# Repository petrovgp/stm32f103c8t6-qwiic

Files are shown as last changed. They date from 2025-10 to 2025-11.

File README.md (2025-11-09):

# STM32F103C8T6 Qwiic-Compatible Breakout Board

A compact and versatile **STM32F103C8T6** breakout board designed in **KiCad 9**, featuring multiple Qwiic-compatible connectors for easy sensor and peripheral integration. Ideal for prototyping, embedded development, and educational use.

## 📸 Board design
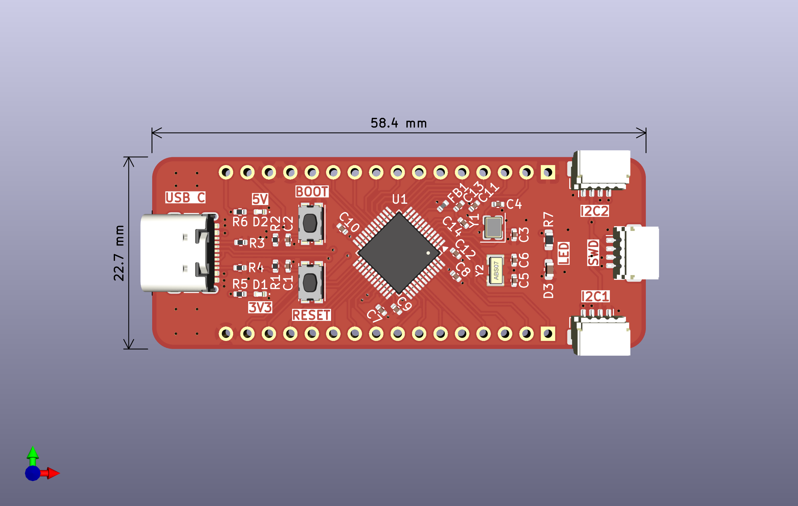
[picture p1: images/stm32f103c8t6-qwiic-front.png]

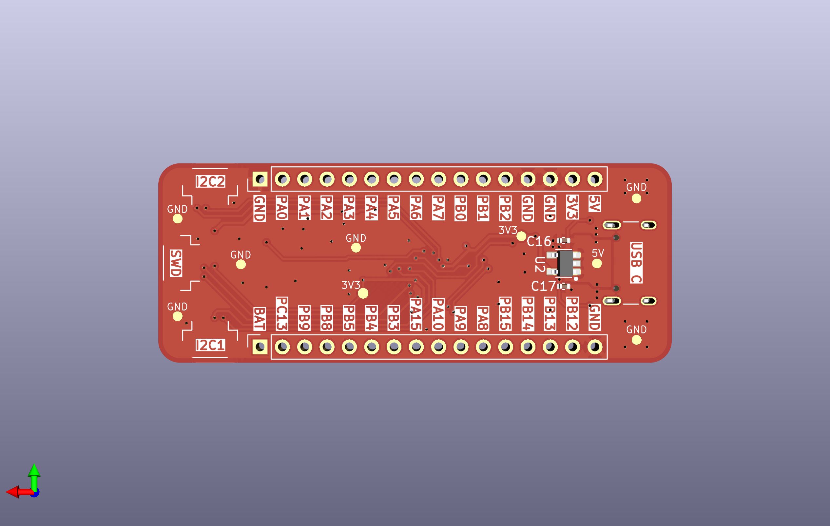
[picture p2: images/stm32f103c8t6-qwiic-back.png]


## 🧠 Features

### ⚡ Core
- **STM32F103C8T6** ARM Cortex-M3 microcontroller (72 MHz, 64 KB Flash, 20 KB RAM)
- Compact and breadboard-friendly **breakout board design**

### 🔋 Power System
- Operable from **3.3 V regulated** or **5 V external input**
- **ME6211C** LDO regulator:
  - 500 mA maximum output current  
  - 100 mV dropout at 100 mA load

### 🔗 Connectivity
- **Qwiic-compatible connectors** for easy plug-and-play I²C expansion:
  - **I²C1 Qwiic port**
  - **I²C2 Qwiic port**
  - **SWD Qwiic port** for programming and debugging
- Clearly labeled GPIO and power pins for easy interfacing

## 🧩 Design Files
All design files were created in **KiCad 9** and production files have been exported with **PCBWay plugin**:
- `schematics/` – full circuit schematics
- `kicad/` – KiCAD 9 project files 
- `kicad/production/` – ready-to-manufacture files (GERBERs + BOM)

Adjustment of production files might be needed. Please check carefully before placing any manufacturing orders.

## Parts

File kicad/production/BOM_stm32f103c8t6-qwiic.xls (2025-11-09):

Designator | Quantity | Value | Footprint | Package | MPN | DNP | Mount_Type | Sim.Pins
C1, C10, C12, C2, C8, C9 | 6 | 100n | C_0402_1005Metric |  | smt | Unpolarized capacitor
C11, C13 | 2 | 1u | C_0402_1005Metric |  | smt | Unpolarized capacitor
C14 | 1 | 10n | C_0402_1005Metric |  | smt | Unpolarized capacitor
C16, C17, C7 | 3 | 10u | C_0402_1005Metric |  | smt | Unpolarized capacitor
C3, C4 | 2 | 6p | C_0402_1005Metric |  | smt | Unpolarized capacitor
C5, C6 | 2 | 15p | C_0402_1005Metric |  | smt | Unpolarized capacitor
D1, D2 | 2 | RED | LED_0402_1005Metric |  | smt | Light emitting diode | 1=K 2=A
D3 | 1 | RED | C_0603_1608Metric |  | smt | Light emitting diode | 1=K 2=A
FB1 | 1 | 120R | L_0402_1005Metric |  | smt | Ferrite bead
J1, J2, J3 | 3 | Conn_01x04_Pin | JST_SH_SM04B-SRSS-TB_1x04-1MP_P1.00mm_Horizontal |  | smt | JST SH 01x04 connector
J6 | 1 | USB_C_USB2.0_14P | USB_C_Receptacle_GCT_USB4105-xx-A_16P_TopMnt_Horizontal |  | smt | USB 2.0-only 14P Type-C Receptacle connector
R1, R2, R3, R4 | 4 | 5.1k | R_0402_1005Metric |  | smt | Resistor
R5, R6 | 2 | 1k | R_0402_1005Metric |  | smt | Resistor
R7 | 1 | 470R | R_0603_1608Metric |  | smt | Resistor
SW1, SW2 | 2 | SW_Push | SW_Push_1P1T_NO_CK_KMR2 |  | smt | Push button switch, generic, two pins
U1 | 1 | STM32F103C8Tx | LQFP-48_7x7mm_P0.5mm |  | smt | STM32F103C8T6
U2 | 1 | ME6211C33M5G-N | SOT-23-5 |  | smt | 3.3V LDO regulator
Y1 | 1 | NX3225SA-16.000M-STD-CSR-1 | Crystal_SMD_3225-4Pin_3.2x2.5mm |  | smt | Four pin crystal, GND on pins 2 and 4
Y2 | 1 | ABS07-32.768KHZ | Crystal_SMD_EuroQuartz_EQ161-2Pin_3.2x1.5mm |  | smt | Two pin crystal

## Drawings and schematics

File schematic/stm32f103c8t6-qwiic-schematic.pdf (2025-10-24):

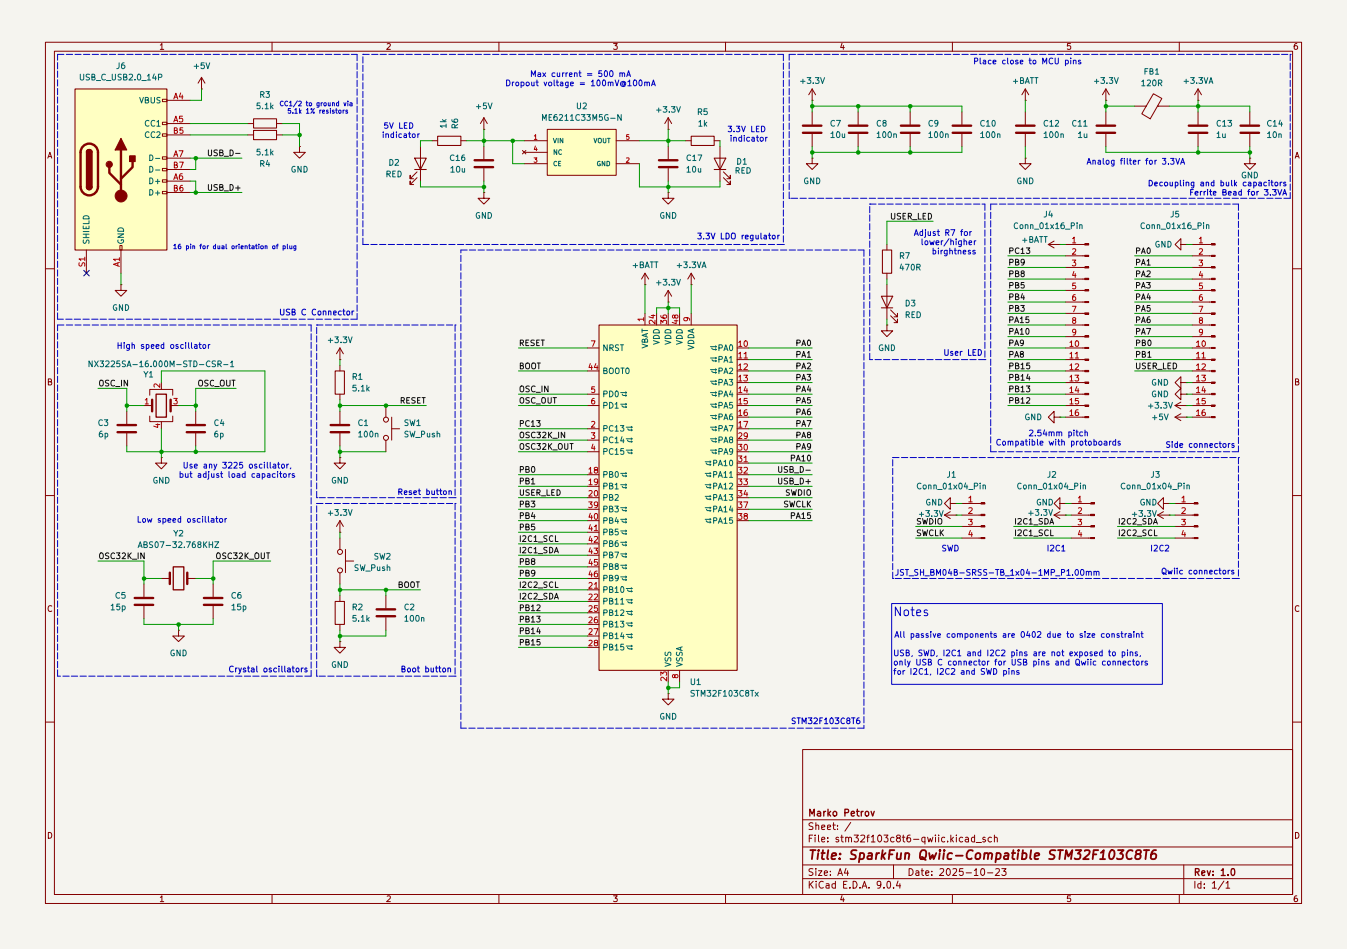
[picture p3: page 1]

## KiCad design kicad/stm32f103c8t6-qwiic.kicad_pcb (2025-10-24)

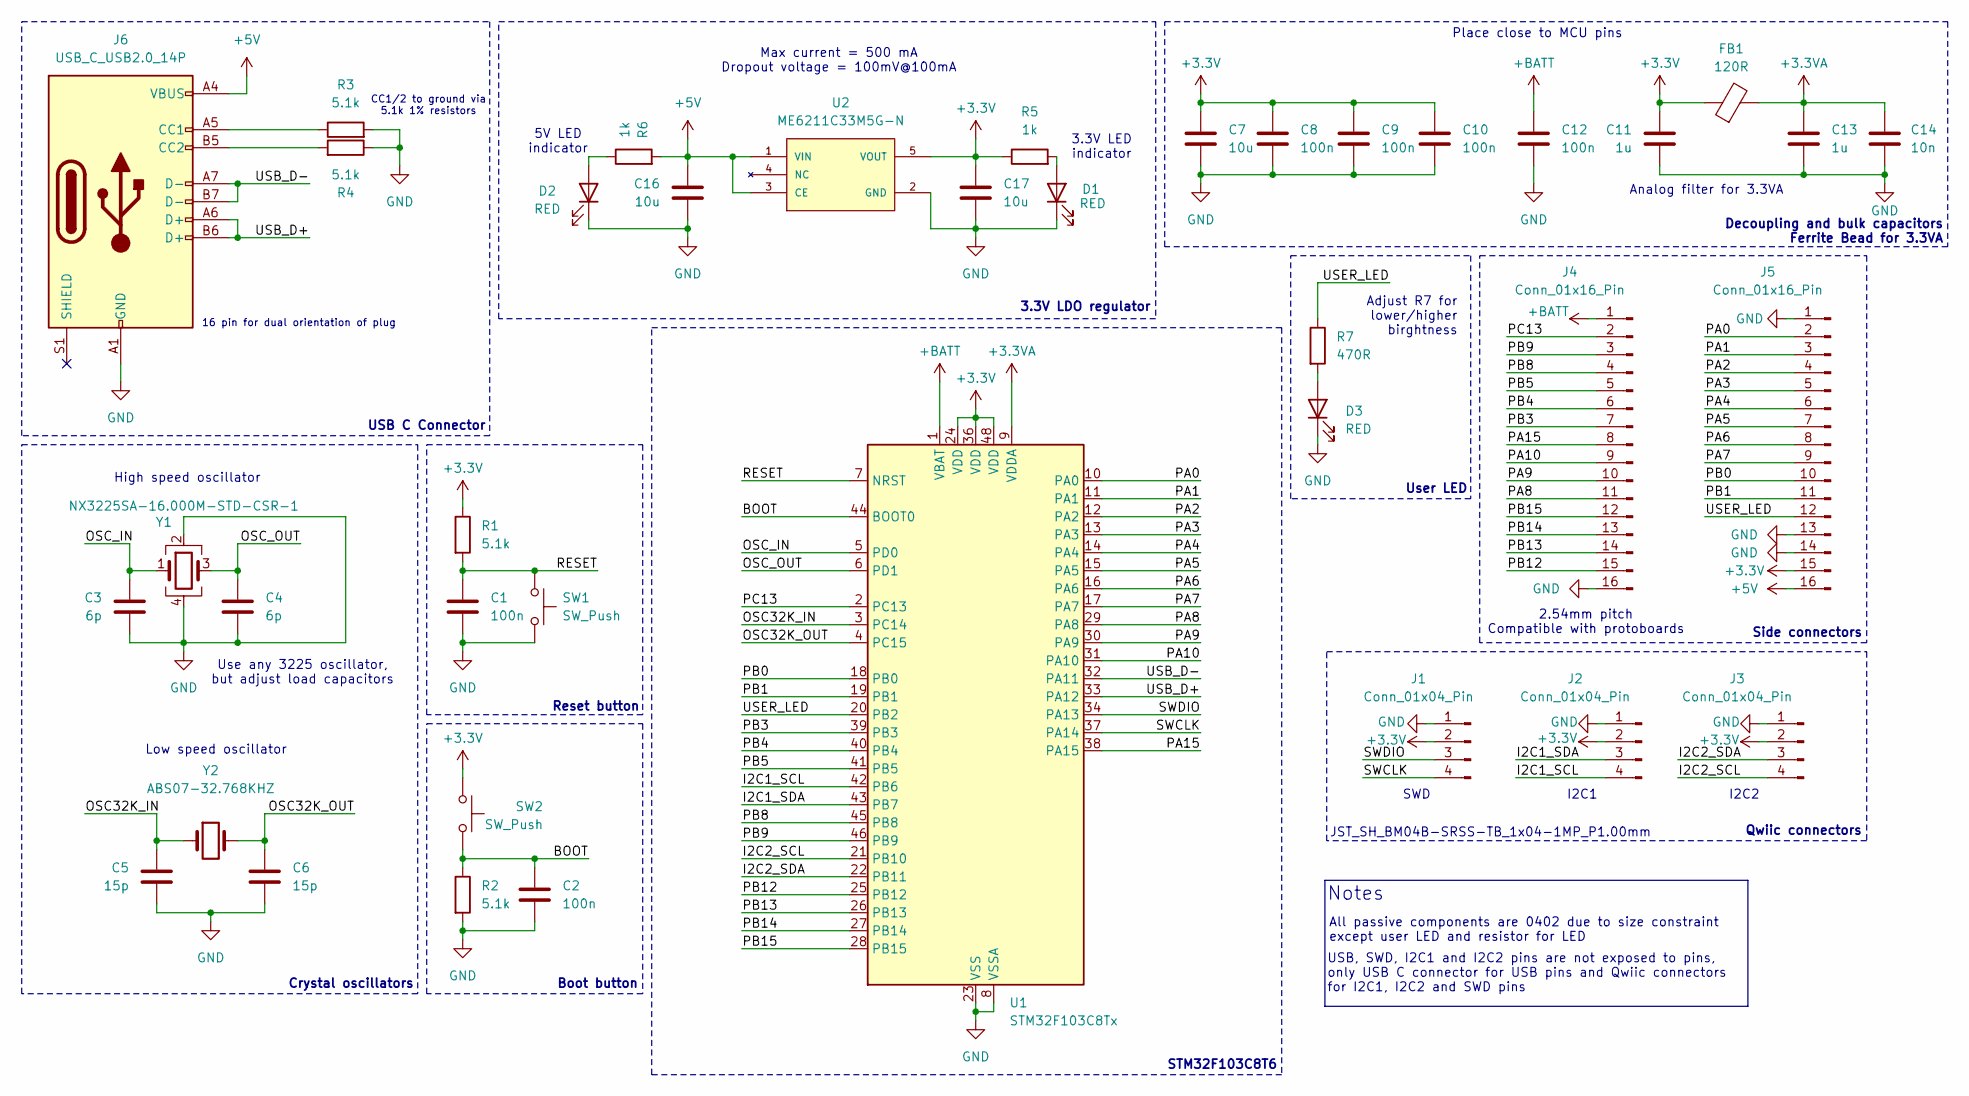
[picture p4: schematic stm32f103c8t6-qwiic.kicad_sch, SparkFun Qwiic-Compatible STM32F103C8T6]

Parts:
C1, C2, C8, C9, C10, C12: 100n; C_0402_1005Metric
C3, C4: 6p; C_0402_1005Metric
C5, C6: 15p; C_0402_1005Metric
C7, C16, C17: 10u; C_0402_1005Metric
C11, C13: 1u; C_0402_1005Metric
C14: 10n; C_0402_1005Metric
D1, D2: RED; LED_0402_1005Metric
D3: RED; C_0603_1608Metric
FB1: 120R; L_0402_1005Metric
J1, J2, J3: Conn_01x04_Pin; JST_SH_SM04B-SRSS-TB_1x04-1MP_P1.00mm_Horizontal
J4, J5: Conn_01x16_Pin; PinHeader_1x16_P2.54mm_Vertical
J6: USB_C_USB2.0_14P; USB_C_Receptacle_GCT_USB4105-xx-A_16P_TopMnt_Horizontal
R1, R2, R3, R4: 5.1k; R_0402_1005Metric
R5, R6: 1k; R_0402_1005Metric
R7: 470R; R_0603_1608Metric
SW1, SW2: SW_Push; SW_Push_1P1T_NO_CK_KMR2
U1: STM32F103C8Tx; LQFP-48_7x7mm_P0.5mm
U2: ME6211C33M5G-N; SOT-23-5
Y1: NX3225SA-16.000M-STD-CSR-1; Crystal_SMD_3225-4Pin_3.2x2.5mm
Y2: ABS07-32.768KHZ; Crystal_SMD_EuroQuartz_EQ161-2Pin_3.2x1.5mm

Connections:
+3.3V: C7.1, C8.1, C9.1, C10.1, C11.1, C17.1, FB1.1, J1.2, J2.2, J3.2, J5.15, R1.1, R5.1, SW2.2, U1.24 (VDD), U1.36 (VDD), U1.48 (VDD), U2.5 (VOUT)
+3.3VA: C13.1, C14.1, FB1.2, U1.9 (VDDA)
+5V: C16.1, J5.16, J6.A4 (VBUS), J6.A9 (VBUS), J6.B4 (VBUS), J6.B9 (VBUS), R6.2, U2.1 (VIN), U2.3 (CE)
+BATT: C12.1, J4.1, U1.1 (VBAT)
/BOOT: C2.1, R2.1, SW2.1, U1.44 (BOOT0)
/I2C1_SCL: J2.4, U1.42 (PB6)
/I2C1_SDA: J2.3, U1.43 (PB7)
/I2C2_SCL: J3.4, U1.21 (PB10)
/I2C2_SDA: J3.3, U1.22 (PB11)
/OSC32K_IN: C5.1, U1.3 (PC14), Y2.1
/OSC32K_OUT: C6.1, U1.4 (PC15), Y2.2
/OSC_IN: C3.1, U1.5 (PD0), Y1.1
/OSC_OUT: C4.1, U1.6 (PD1), Y1.3
/PA0: J5.2, U1.10 (PA0)
/PA1: J5.3, U1.11 (PA1)
/PA2: J5.4, U1.12 (PA2)
/PA3: J5.5, U1.13 (PA3)
/PA4: J5.6, U1.14 (PA4)
/PA5: J5.7, U1.15 (PA5)
/PA6: J5.8, U1.16 (PA6)
/PA7: J5.9, U1.17 (PA7)
/PA8: J4.11, U1.29 (PA8)
/PA9: J4.10, U1.30 (PA9)
/PA10: J4.9, U1.31 (PA10)
/PA15: J4.8, U1.38 (PA15)
/PB0: J5.10, U1.18 (PB0)
/PB1: J5.11, U1.19 (PB1)
/PB3: J4.7, U1.39 (PB3)
/PB4: J4.6, U1.40 (PB4)
/PB5: J4.5, U1.41 (PB5)
/PB8: J4.4, U1.45 (PB8)
/PB9: J4.3, U1.46 (PB9)
/PB12: J4.15, U1.25 (PB12)
/PB13: J4.14, U1.26 (PB13)
/PB14: J4.13, U1.27 (PB14)
/PB15: J4.12, U1.28 (PB15)
/PC13: J4.2, U1.2 (PC13)
/RESET: C1.1, R1.2, SW1.1, U1.7 (NRST)
/SWCLK: J1.4, U1.37 (PA14)
/SWDIO: J1.3, U1.34 (PA13)
/USB_D+: J6.A6 (D+), J6.B6 (D+), U1.33 (PA12)
/USB_D-: J6.A7 (D-), J6.B7 (D-), U1.32 (PA11)
/USER_LED: J5.12, R7.1, U1.20 (PB2)
GND: C1.2, C2.2, C3.2, C4.2, C5.2, C6.2, C7.2, C8.2, C9.2, C10.2, C11.2, C12.2, C13.2, C14.2, C16.2, C17.2, D1.1 (K), D2.1 (K), D3.1 (K), J1.1, J2.1, J3.1, J4.16, J5.1, J5.13, J5.14, J6.A1 (GND), J6.A12 (GND), J6.B1 (GND), J6.B12 (GND), R2.2, R3.2, R4.1, SW1.2, U1.8 (VSSA), U1.23 (VSS), U1.35 (VSS), U1.47 (VSS), U2.2 (GND), Y1.2, Y1.4
unnamed: D1.2 (A), R5.2
unnamed: D2.2 (A), R6.1
unnamed: D3.2 (A), R7.2
unnamed: J6.A5 (CC1), R3.1
unnamed: J6.B5 (CC2), R4.2

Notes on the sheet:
Reset button
Analog filter for 3.3VA
Low speed oscillator
I2C1
3.3V LED indicator
Place close to MCU pins
Adjust R7 for lower/higher birghtness
Boot button
SWD
CC1/2 to ground via 5.1k 1% resistors
Crystal oscillators
User LED
5V LED indicator
Decoupling and bulk capacitors Ferrite Bead for 3.3VA
USB, SWD, I2C1 and I2C2 pins are not exposed to pins, only USB C connector for USB pins and Qwiic connectors for I2C1, I2C2 and SWD pins
2.54mm pitch Compatible with protoboards
USB C Connector
STM32F103C8T6
3.3V LDO regulator
All passive components are 0402 due to size constraint except user LED and resistor for LED
Max current = 500 mA Dropout voltage = 100mV@100mA
16 pin for dual orientation of plug
Side connectors
Notes
High speed oscillator
I2C2
Use any 3225 oscillator, but adjust load capacitors
JST_SH_BM04B-SRSS-TB_1x04-1MP_P1.00mm
Qwiic connectors

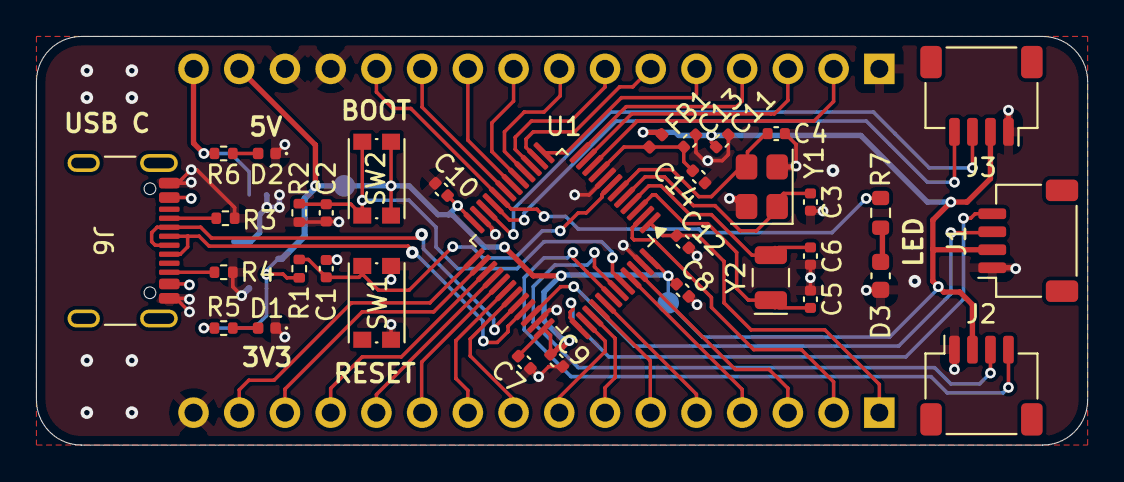
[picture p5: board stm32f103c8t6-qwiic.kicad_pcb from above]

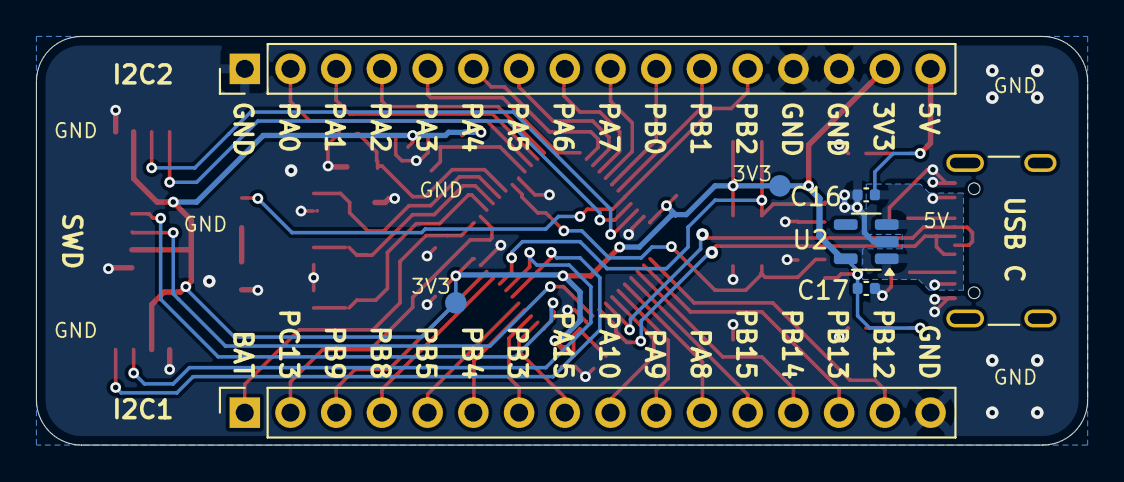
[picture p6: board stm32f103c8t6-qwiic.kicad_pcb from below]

Board: 2 copper layers, 58.4 x 22.7 mm, 39 parts (5 on the bottom side), 49 nets.

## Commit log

2025-10-22 Add board design images
2025-10-24 Add schematic
2025-10-24 Add KiCAD 9 project and production files
    [bom.csv, designators.csv, positions.csv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]
2025-10-24 Update KiCAD files due to wrong footprint BM04B was chosen instead of SM04B for the Qwiic connectors. This commit updates the footprints, layout and production files.
    [bom.csv, positions.csv, stm32f103c8t6-qwiic.kicad_pcb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]
2025-11-09 Update production files
    [BOM_stm32f103c8t6-qwiic.xls, bom.csv, designators.csv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]
